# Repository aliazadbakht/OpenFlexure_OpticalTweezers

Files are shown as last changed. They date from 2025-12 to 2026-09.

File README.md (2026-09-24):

# OpenFlexure Optical Tweezers

An extension for the [OpenFlexure Microscope](https://openflexure.org/) that adds optical tweezers functionality. The OpenFlexure Project provides open-source, 3D-printed microscopes with precise mechanical positioning — this project extends that capability with laser-based optical trapping.

## Demo Video

Watch on YouTube (https://youtu.be/GGlHxX-9Ro8)

Full assembly walkthrough covering the basics, required parts, and what you need to get started. Click the thumbnail to watch on YouTube.

## Try the Interactive Simulation

**[Launch Web Simulation →](https://aliazadbakht.github.io/OpenFlexure_OpticalTweezers/)**

Experience optical tweezers physics directly in your browser! Click and drag particles, watch them escape the trap, and observe real-time Brownian motion. No installation required — works on any device.

---

## Table of Contents

- [Project Structure](#project-structure)
- [What's Included](#whats-included)
- [Installation](#installation)
- [Usage Guide](#usage-guide)
  - [Optical Tweezers Simulation](#1-optical-tweezers-simulation)
  - [Microrheology Simulation](#2-microrheology-simulation)
- [Building the Hardware](#building-the-hardware)
- [Bill of Materials](#bill-of-materials)
- [Acknowledgments](#acknowledgments)
- [License](#license)

---

## Project Structure

```
OpenFlexureOT/
├── README.md                          # This file
├── BOM.md                             # Bill of materials
├── LICENSE                            # CERN-OHL-S v2
├── index.html                         # GitHub Pages landing page
├── requirements.txt                   # Python dependencies (simulation)
│
├── Optical Tweezers Simulation/       # Interactive physics simulation
│   ├── opticaltweezers_simulation.py  # Desktop Python version
│   ├── index.html                     # Web version (PyScript, runs in browser)
│   ├── requirements.txt               # Python dependencies
│   ├── README.md                      # Simulation-specific documentation
│   └── DEPLOYMENT.md                  # GitHub Pages deployment guide
│
├── Microrheology Simulation/          # Browser-based microrheology demo
│   ├── Microrheology simulation.html
│   └── deploy/
│
├── openscad/                          # Parametric CAD files for customization
│   ├── cube_OT.scad
│   ├── laser_holder_OT.scad
│   ├── rms_optics_module_ot.scad
│   ├── cuppler_ot.scad
│   ├── alignment_cap.scad
│   ├── alignment_tool.scad
│   └── libs/
│
├── ipt/                               # Autodesk Inventor files (.ipt, .iam)
│
└── stl/                               # Ready-to-print STL and 3MF files
```

---

## What's Included

### CAD Files
- **`ipt/`** — Autodesk Inventor source files (.ipt/.iam) for modification in Fusion 360 or Inventor
- **`openscad/`** — Parametric OpenSCAD designs for customization (laser diameter, thread sizing, etc.)
- **`stl/`** — Ready-to-print STL and 3MF files for 3D printing

### Simulation Software
- **Optical Tweezers Simulation** — Interactive physics simulation (web + desktop)
- **Microrheology Simulation** — Browser-based microrheology demo

### Tractor-Beam Canvas Demo (Embeddable)
A lightweight, pure HTML/JS optical tweezers animation that runs in any browser. You can copy the canvas section and script from the main `index.html` and embed it into your own website — no dependencies required.

---

## Installation

### Prerequisites

- **Python 3.11+** (required for simulation software)
- **Git** (to clone the repository)

### Step 1: Clone the Repository

```bash
git clone https://github.com/aliazadbakht/OpenFlexureOT.git
cd OpenFlexureOT
```

### Step 2: Create a Virtual Environment (Recommended)

```bash
python -m venv venv

# On macOS/Linux:
source venv/bin/activate

# On Windows:
venv\Scripts\activate
```

### Step 3: Install Dependencies

```bash
pip install -r requirements.txt
```

---

## Usage Guide

### 1. Optical Tweezers Simulation

An interactive simulation of optical trap physics including Brownian motion, trap escape dynamics, and force visualization.

#### Web Version (No Installation)

Visit **[https://aliazadbakht.github.io/OpenFlexure_OpticalTweezers/](https://aliazadbakht.github.io/OpenFlexure_OpticalTweezers/)**

- Works on any device (desktop, tablet, mobile)
- First load takes 10–30 seconds (downloads Python runtime)
- Fully interactive with click-and-drag

#### Desktop Version

```bash
cd "Optical Tweezers Simulation"
pip install -r requirements.txt
python opticaltweezers_simulation.py
```

**Controls:**
- **Click and hold** on the particle to grab it
- **Drag** the particle around to move it
- **Release** inside the trap zone — the particle snaps back
- **Release** outside the escape radius — the particle escapes

**What you'll see:**
- Real-time Brownian motion of a trapped particle
- Green arrows showing trap force (in piconewtons)
- Position histogram with Boltzmann distribution overlay
- Time-series plot of particle position

---

### 2. Microrheology Simulation

Open `Microrheology Simulation/Microrheology simulation.html` in any web browser. No installation required.

---

## Building the Hardware

### Prerequisites

1. A 3D printer (PLA or PETG recommended)
2. OpenFlexure Microscope base — see [OpenFlexure documentation](https://openflexure.org/projects/microscope/)
3. Laser diode (typically 635 nm red, ~1 mW)
4. High-NA objective lens (NA >= 0.8, RMS threaded)
5. Optical components listed in [BOM.md](BOM.md)

### Assembly Steps

1. **Print the parts** — use the STL files from `stl/` or the combined `OpenFlexure Optical Tweezers.3mf`
2. **Install brass heat-set inserts** into the laser holder (3x M3)
3. **Mount the dichroic mirror** inside the optical cube
4. **Install the lenses** (f=17–20mm doublet and f=50mm doublet)
5. **Mount the laser** into the laser holder with adjustment screws
6. **Attach the coupler** between the cube and laser holder
7. **Install the objective** into the RMS optics module
8. **Mount onto the OpenFlexure Microscope** base

Watch the [assembly video](https://youtu.be/GGlHxX-9Ro8) for a detailed walkthrough.

### Customizing with OpenSCAD

The OpenSCAD files require dependencies from the main OpenFlexure project:

```bash
# 1. Clone the OpenFlexure Microscope repository
git clone https://gitlab.com/openflexure/openflexure-microscope.git

# 2. Install the threads library inside this project's OpenSCAD folder
cd OpenFlexureOT
git clone https://github.com/rcolyer/threads-scad.git openscad/threads-scad
```

Keep the folder structure like this:

```
your-workspace/
├── openflexure-microscope/
│   └── openscad/               # OpenFlexure base files
└── OpenFlexureOT/
    └── openscad/               # This project's files
        ├── threads-scad/
        ├── libs/
        └── *.scad
```

Customize parameters in the SCAD files:
- `laser_diameter` — match your laser diode size (default: 6 mm)
- Thread dimensions for your specific hardware
- Mounting geometry

Render and export STL files from OpenSCAD.

---

## Bill of Materials

See [BOM.md](BOM.md) for the full list of components including optical parts, fasteners, and electronics.

---

## Acknowledgments

This project is supported by **[Wavefront Principle B.V.](https://wfront.nl/)**, a pre-incubator dedicated to transforming innovative ideas into real-world devices.

It is also supported by **[Precisometer B.V.](https://www.precisometer.com)**, a company specialized in microscopy.

Special thanks to **[Mojtaba Nosratloo](https://www.linkedin.com/in/mojtaba-nosratlo-b62404a9/)** for his significant contributions to the design and development of this project.

---

## License

This project is licensed under the CERN Open Hardware Licence Version 2 — Strongly Reciprocal (CERN-OHL-S v2). See the [LICENSE](LICENSE) file for details.

This license is used because this project incorporates and builds upon OpenFlexure designs and components.

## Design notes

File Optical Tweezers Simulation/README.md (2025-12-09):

# Interactive Optical Tweezers Simulation

A real-time interactive simulation of optical tweezers (optical traps) using Python. Grab and manipulate a colloidal particle to observe trap dynamics, escape behavior, and thermal fluctuations.

## Features

🎯 **Interactive Particle Manipulation**
- Click and drag the particle to move it around
- Release inside the trap zone → particle bounces back to center
- Release outside the escape zone → particle escapes the optical trap
- Drag escaped particles back to recapture them

📊 **Real-time Visualization**
- **Top-down view**: See particle position and trajectory
- **Time series**: Track x-position over time relative to trap center
- **Histogram**: Distribution of particle positions (compared with Boltzmann theory)
- **Status indicators**: Visual feedback on trap state (trapped/dragging/escaped)
- **Force visualization**: Green arrow showing trap force magnitude and direction in real-time (piconewtons)

⚙️ **Physical Accuracy**
- Langevin equation with proper trap stiffness
- Realistic Brownian motion from thermal fluctuations
- Escape dynamics based on trap potential
- Boltzmann distribution for equilibrium predictions

## Requirements

- Python 3.8+
- NumPy
- Matplotlib
- SciPy

## Installation

```bash
git clone https://github.com/aliazadbakht/optical-tweezers-simulation.git
cd optical-tweezers-simulation
pip install -r requirements.txt
```

## Usage

Simply run the simulation:

```bash
python opticaltweezers_simulation.py
```

### Controls

| Action | Result |
|---|---|
| **Click particle** | Start dragging |
| **Drag** | Move particle to cursor |
| **Release inside orange circle** | Particle rebounds to trap center |
| **Release outside orange circle** | Particle escapes trap (Brownian motion only) |
| **Drag escaped particle back** | Recapture into trap |

## Physical Parameters

- **Particle**: 4 µm silica colloid
- **Laser power**: 5 mW @ 635 nm (red laser)
- **Trap stiffness**: 1.5 × 10⁻⁶ N/m
- **Temperature**: 293 K (20°C)
- **Medium**: Water (η = 0.001 Pa·s)
- **Escape radius**: 4 µm (beyond this, particle escapes)

## How It Works

The simulation integrates the Langevin equation:

$$m\frac{dv}{dt} = -\gamma v + F_{trap} + F_{thermal}$$

Where:
- $\gamma$ = friction coefficient from Stokes drag
- $F_{trap}$ = Harmonic trap force (when inside escape radius)
- $F_{thermal}$ = Random thermal forces
- $m$ = particle mass (negligible for small particles)

## Understanding the Visualization

### Trap Force Display
When dragging or holding the particle, a **green arrow** displays the trap force in real-time:
- **Arrow direction**: Points toward trap center (direction of force)
- **Arrow magnitude**: Scales with force strength
- **Force values**: Displayed in piconewtons (pN) for Fx, Fy, and |F|

The trap force follows Hooke's law: $$F = -k \cdot r$$

Where:
- $k$ = trap stiffness (1.5 × 10⁻⁶ N/m)
- $r$ = displacement from trap center

Typical force values at different positions:
- At trap center (r = 0): F = 0 pN
- At 1 µm displacement: F ≈ 1.5 pN
- At 4 µm (escape radius): F ≈ 6 pN

### Position Histogram
When the particle is trapped and near equilibrium, the histogram shows the **Boltzmann distribution** (black dashed line). This represents the theoretical probability of finding the particle at different positions due to thermal fluctuations.

The standard deviation of this distribution is:
$$\sigma = \sqrt{\frac{k_B T}{k}}$$

### Time Series
The x-position plot shows the particle's center coordinate relative to the trap center (0). The orange dashed lines indicate the escape radius boundaries.

## Applications

This simulation demonstrates:
- Optical trap fundamentals and dynamics
- Brownian motion and thermal noise
- Escape events and rare trajectory sampling
- Potential applications in:
  - Biophysics (protein pulling, molecular mechanics)
  - Colloidal science
  - Soft matter physics
  - Single-molecule studies

## Tips for Exploration

1. **Gentle Release**: Release the particle just outside the trap → watch it hover around the boundary before escaping
2. **Hard Pull**: Drag far and release → observe escape with asymmetric trajectory
3. **Recapture**: Escape a particle and drag it slowly back to observe re-entry dynamics
4. **Thermal Fluctuations**: At rest in the trap, the particle jitters randomly - this is Brownian motion!

## License

This simulation is part of the OpenFlexure Optical Tweezers project and is licensed under the CERN Open Hardware Licence Version 2 - Strongly Reciprocal (CERN-OHL-S v2).

## Author

Created for educational purposes in optical trapping and computational physics.

## References

- A. Ashkin, J. M. Dziedzic, J. E. Bjorkholm, and S. Chu, "Observation of a single-beam gradient force optical trap for dielectric particles," Opt. Lett. 11, 288-290 (1986)
- K. Berg-Sørensen and H. Flyvbjerg, "Power spectrum analysis for optical tweezers," Rev. Sci. Instrum. 75, 594-612 (2004)
- W. J. Greenleaf, M. T. Woodside, and S. M. Block, "High-resolution, single-molecule measurements of biomolecular motion," Annu. Rev. Biophys. Biomol. Struct. 36, 171-190 (2007)

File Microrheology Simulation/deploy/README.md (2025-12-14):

# Optical Tweezers Microrheology Simulation

An interactive simulation demonstrating passive microrheology using optical tweezers. Probe the viscoelastic properties of different media by analyzing the Brownian motion of a trapped bead.

## Features

🔬 **Multiple Media Types**
- **Newtonian Fluids**: Water, 50% Glycerol, 80% Glycerol
- **Viscoelastic Polymers**: Dilute PEO (0.1%), Semi-dilute (1%), Entangled (5%)
- **Gels**: Weak Agarose (0.1%), Strong Agarose (1%)

📊 **Real-time Visualizations**
- **Trapped Bead**: Watch Brownian motion change with medium properties
- **Dynamic Moduli**: G'(ω) and G''(ω) vs frequency (log-log plot)
- **Complex Viscosity**: |η*(ω)| vs frequency
- **Mean Square Displacement (MSD)**: Computed from particle trajectory

⚙️ **Physical Parameters**
- 2 µm silica bead
- 1 pN/µm trap stiffness
- Temperature: 293 K (20°C)
- Maxwell viscoelastic model

## Physics Background

### Microrheology Principles

Passive microrheology extracts viscoelastic properties from thermal fluctuations of embedded probe particles. The Mean Square Displacement (MSD) relates to the complex modulus through the Generalized Stokes-Einstein Relation.

### Dynamic Moduli

- **G' (Storage Modulus)**: Elastic/solid-like response - energy stored per cycle
- **G'' (Loss Modulus)**: Viscous/liquid-like response - energy dissipated per cycle

### Maxwell Model

For viscoelastic media:
- Short relaxation times: Liquid-like behavior (high G'')
- Long relaxation times: Gel-like behavior (high G')
- Crossover frequency indicates transition from viscous to elastic dominance

## How to Use

1. **Launch the simulation** by opening this page
2. **Select a medium** from the dropdown to change fluid properties
3. **Observe the bead motion** - see how Brownian motion varies with media
4. **Analyze the results**:
   - MSD curve shows particle displacement behavior
   - G' and G'' show elastic vs viscous contributions
   - Compare different media to understand viscoelasticity

## Applications

This simulation demonstrates principles used in:

- **Biophysics**: Cell mechanics, cytoplasm rheology
- **Soft Matter**: Polymer solutions, hydrogels
- **Pharmaceutical**: Drug delivery gel characterization
- **Food Science**: Texture analysis
- **Materials Science**: Complex fluid characterization

## Technical Details

- **Bead diameter**: 2 µm (silica)
- **Trap stiffness**: 1 pN/µm
- **Temperature**: 293 K (20°C)
- **Simulation**: PyScript (Python in browser)

## License

This simulation is part of the OpenFlexure Optical Tweezers project and is licensed under the CERN Open Hardware Licence Version 2 - Strongly Reciprocal (CERN-OHL-S v2).

---

**Questions?** Open an issue on the GitHub repository!

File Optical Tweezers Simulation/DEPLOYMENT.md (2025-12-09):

# Deploying the Optical Tweezers Simulation to GitHub Pages

This guide will help you deploy your interactive optical tweezers simulation to GitHub Pages so anyone can access it via a web browser.

## 🚀 Quick Deployment Steps

### Option 1: Deploy from the Repository Root (Recommended)

1. **Move the HTML file to the repository root:**
   ```bash
   cp "Optical Tweezers Simulation/index.html" index.html
   ```

2. **Commit and push to GitHub:**
   ```bash
   git add index.html
   git commit -m "Add PyScript optical tweezers simulation for GitHub Pages"
   git push origin main
   ```

3. **Enable GitHub Pages:**
   - Go to your repository on GitHub: `https://github.com/yourusername/OpenFlexureOT`
   - Click **Settings** → **Pages** (in the left sidebar)
   - Under **Source**, select **Deploy from a branch**
   - Under **Branch**, select `main` and `/ (root)`
   - Click **Save**

4. **Access your simulation:**
   - GitHub will provide a URL like: `https://yourusername.github.io/OpenFlexureOT/`
   - Wait 1-2 minutes for deployment to complete
   - Visit the URL to see your simulation!

### Option 2: Deploy from a Specific Folder

1. **Create a `docs` folder and move the file:**
   ```bash
   mkdir -p docs
   cp "Optical Tweezers Simulation/index.html" docs/index.html
   ```

2. **Commit and push:**
   ```bash
   git add docs/
   git commit -m "Add simulation to docs folder for GitHub Pages"
   git push origin main
   ```

3. **Enable GitHub Pages:**
   - Go to **Settings** → **Pages**
   - Select branch `main` and folder `/docs`
   - Click **Save**

4. **Access:** `https://yourusername.github.io/OpenFlexureOT/`

### Option 3: Deploy to a Separate Branch (gh-pages)

1. **Create and switch to gh-pages branch:**
   ```bash
   git checkout -b gh-pages
   ```

2. **Keep only the HTML file:**
   ```bash
   cp "Optical Tweezers Simulation/index.html" index.html
   git add index.html
   git commit -m "Initial GitHub Pages deployment"
   git push origin gh-pages
   ```

3. **Switch back to main:**
   ```bash
   git checkout main
   ```

4. **Enable GitHub Pages:**
   - Go to **Settings** → **Pages**
   - Select branch `gh-pages` and `/ (root)`
   - Click **Save**

## 📝 Important Notes

### First Load Time
- **Initial load takes 10-30 seconds** because PyScript downloads Python runtime and libraries
- Subsequent interactions are fast
- This is normal for PyScript applications

### Browser Compatibility
- Works best in **Chrome, Firefox, Edge, Safari** (latest versions)
- Requires JavaScript enabled
- Some older browsers may not support WebAssembly

### File Size
- The HTML file is self-contained (no external dependencies except PyScript CDN)
- All Python code is embedded in the HTML
- No need to upload additional files

## 🔧 Customization

### Update GitHub Link
In `index.html`, find this line and update with your actual GitHub username:
```html
<p>Built with PyScript | <a href="https://github.com/yourusername/OpenFlexureOT" target="_blank">View on GitHub</a></p>
```

Change `yourusername` to your actual GitHub username.

### Change Simulation Parameters
Edit the parameters in the `OpticalTrapSimulation.__init__()` method:
- `self.power` - Laser power (5.0e-3 = 5 mW)
- `self.wavelength` - Laser wavelength (635e-9 = 635 nm)
- `self.d_p` - Particle diameter (4.0e-6 = 4 µm)
- `self.stiffness` - Trap stiffness (1.5e-6 N/m)

## 🐛 Troubleshooting

### Simulation doesn't load
- Check browser console for errors (F12)
- Ensure you have a stable internet connection (PyScript loads from CDN)
- Clear browser cache and reload

### Simulation is slow
- This is expected on first load
- Close other browser tabs to free up memory
- Try a different browser (Chrome usually performs best)

### 404 Error on GitHub Pages
- Wait 2-5 minutes after enabling Pages
- Check that `index.html` is in the correct location
- Verify the branch/folder settings in GitHub Pages settings

## 🌐 Sharing Your Simulation

Once deployed, share your simulation with:
- **Direct link:** `https://yourusername.github.io/OpenFlexureOT/`
- **QR Code:** Generate a QR code pointing to your URL
- **Embed:** Can be embedded in other websites using an iframe

## 📚 Additional Resources

- [PyScript Documentation](https://pyscript.net/)
- [GitHub Pages Documentation](https://docs.github.com/en/pages)
- [Original Simulation](../Optical%20Tweezers%20Simulation/opticaltweezers_simulation.py)

## ✨ What's Different from the Python Version?

The PyScript version:
- ✅ Runs in any web browser (no Python installation needed)
- ✅ Can be hosted on GitHub Pages for free
- ✅ Same physics simulation and interactivity
- ✅ Same visual appearance
- ⏱️ Slower initial load time (10-30 seconds)
- 🌐 Requires internet connection for first load

## 🎓 For Academic Use

If using this simulation for teaching or research:
1. Consider adding a citation/acknowledgment section
2. You can modify the instructions for your specific use case
3. The simulation accurately represents Brownian motion in optical traps
4. Parameters are based on realistic experimental values

---

**Need help?** Open an issue on the GitHub repository!

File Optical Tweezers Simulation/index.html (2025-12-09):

# 🔬 Interactive Optical Tweezers Simulation

Real-time Brownian Motion in an Optical Trap

### 📋 How to Use:

- Click on the blue particle to grab it
- Drag it around the trap area
- Release inside the orange circle → particle bounces back to center (trapped!)
- Release outside the orange circle → particle ESCAPES!
- Drag back an escaped particle to recapture it
- Watch the green arrow show the trap force magnitude and direction

Loading simulation... (This may take 10-30 seconds on first load)

Simulates a 4µm silica bead in a 5mW optical trap at 635nm wavelength

Built with PyScript | View on GitHub (https://github.com/aliazadbakht/OpenFlexureOT)

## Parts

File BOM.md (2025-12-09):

# Bill of Materials (BOM)

## Optical Components

| Item | Specification | Quantity | Where to Buy |
|---|---|---|---|
| High-NA Objective Lens | NA ≥ 0.8, RMS threaded (search: "Plan infinity Achromatic Objective") | 1 | [AliExpress](https://nl.aliexpress.com/item/1005009852515331.html) |
| Red Laser Diode | ~1 mW (laser pointer), 635 nm typical | 1 | [Amazon](https://www.amazon.nl/-/en/dp/B07RM3RWSF?ref_=ppx_hzsearch_conn_dt_b_fed_asin_title_1) |
| Doublet Lens | Ø 12.7 mm (½"), f = 17–20 mm (search: "Double-Cemented Achromatic Lenses")| 1 | [AliExpress](https://nl.aliexpress.com/item/1005009623444048.html) |
| Doublet Lens | Ø 12.7 mm (½"), f = 50 mm (search: "Double-Cemented Achromatic Lenses")| 1 | [AliExpress](https://nl.aliexpress.com/item/1005009623444048.html) |
| Dichroic Mirror | Reflects red (~635 nm), pass blue, green 15x10x1.1mm  | 1 | [AliExpress](https://nl.aliexpress.com/item/4000835210707.html) |

## 3D-Printed Parts

| Item | File Location | Quantity | Where to Buy |
|---|---|---|---|
| Optical Cube | `stl/` folder | 1 | N/A - Print yourself |
| Cube-Laser Coupler | `stl/` folder | 1 | N/A - Print yourself |
| Laser Holder (3-screw adjust) | `stl/` folder | 1 | N/A - Print yourself |
| Additional mounting parts | `stl/OpenFlexure Optical Tweezers.3mf` | As needed | N/A - Print yourself |

## Hardware & Fasteners

| Item | Specification | Quantity | Where to Buy |
|---|---|---|---|
| Brass Heat-Set Inserts | M3 thread | 3 | [Amazon](https://www.amazon.nl/-/en/dp/B09ZHSGHXD?ref_=ppx_hzsearch_conn_dt_b_fed_asin_title_4&th=1) |
| M3 Screws | same as used in actuators/condenser (length as needed) | 3 | |
| M2 Self-Tapping Screws | For plastic parts | 4 | |
| M3 × 6 mm Screws | Machine screws | 2 | |

## Electronics (Optional)

| Item | Specification | Quantity | Where to Buy |
|---|---|---|---|
| DC-DC Buck/Boost Converter | Adjustable output to match laser voltage | 1 | [Amazon](https://www.amazon.nl/-/en/dp/B0D7BWSTCX?ref_=ppx_hzsearch_conn_dt_b_fed_asin_title_3) |
| USB Power Adapter | 5V output (if powering via USB) | 1 | |

## Notes

- **Objective Lens**: Must be high numerical aperture (NA ≥ 0.8) for effective optical trapping. RMS thread compatible with OpenFlexure microscope.
- **Laser Safety**: Use appropriate eye protection when working with lasers, even low-power ones.
- **3D Printing**: All STL files are in the `stl/` folder. Print with standard PLA or PETG.
- **Brass Inserts**: Install with soldering iron or heat-set tool before assembly.
- **DC-DC Converter**: Only needed if your laser operating voltage differs from your power supply (e.g., laser needs 3V but you have 5V USB).

## OpenFlexure Base Components

This extension requires a complete OpenFlexure Microscope base. See the [OpenFlexure documentation](https://openflexure.org/projects/microscope/) for the full microscope BOM.

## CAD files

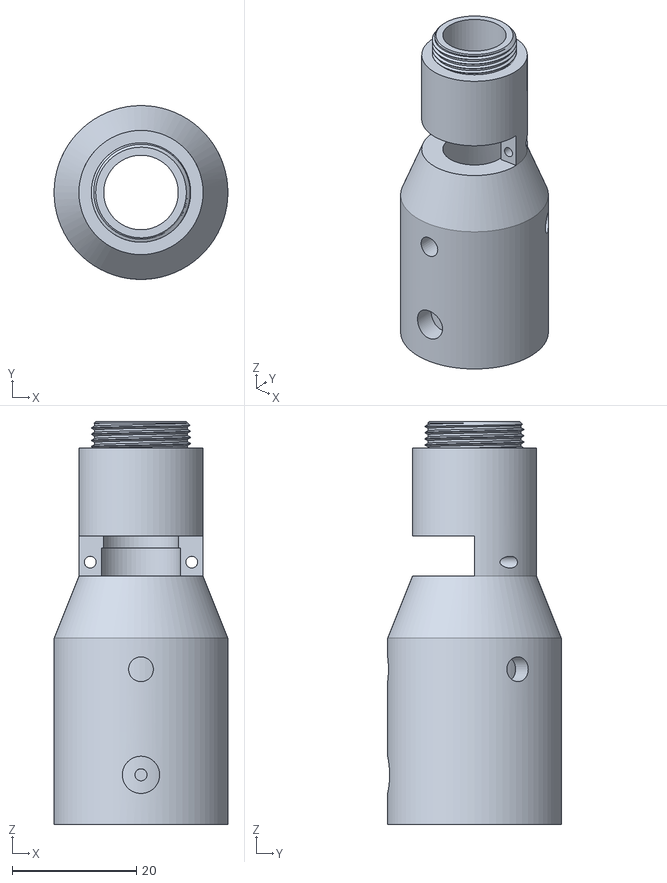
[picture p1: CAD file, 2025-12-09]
stl/Laser Holder 12 mm laser.stl
28.0 x 28.0 x 64.9

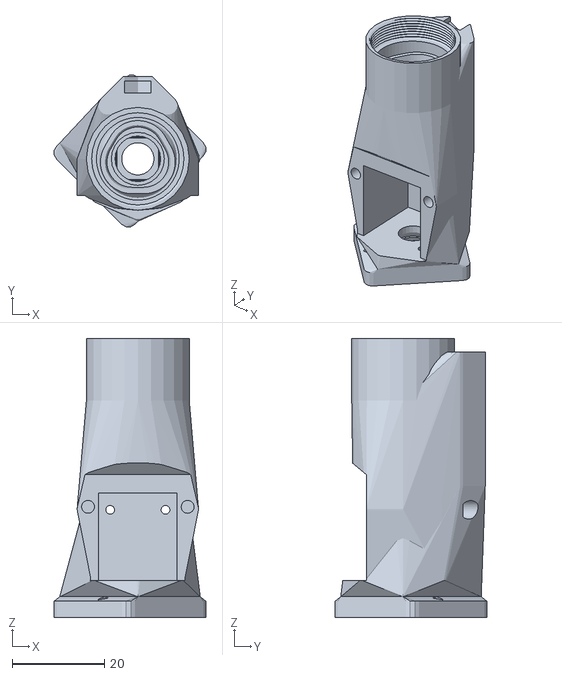
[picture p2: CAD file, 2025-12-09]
stl/RMS optics module OT.stl
32.9 x 32.9 x 60.5

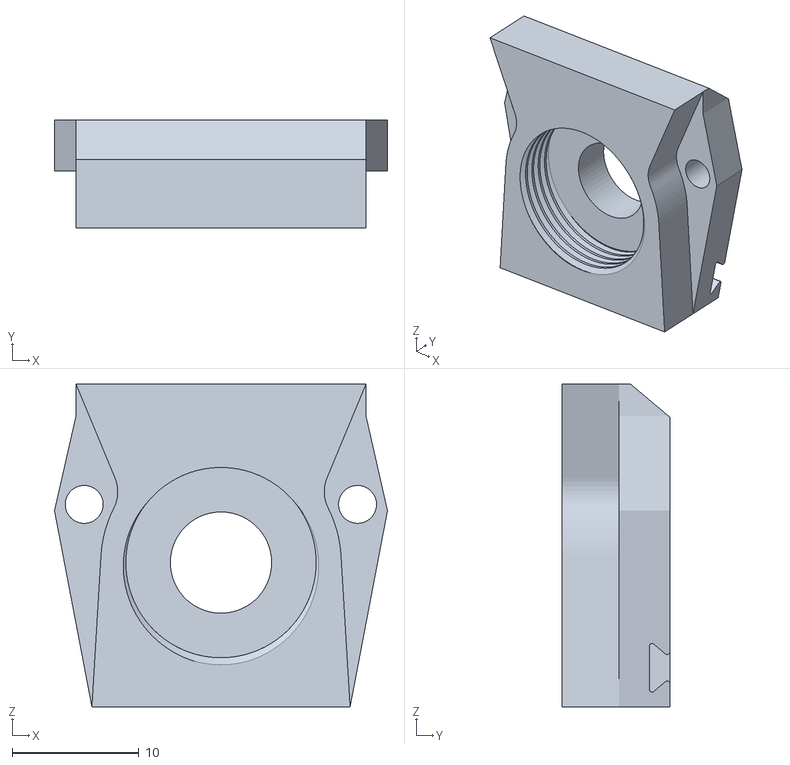
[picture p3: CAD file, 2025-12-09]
stl/Cuppler.stl
26.3 x 8.50 x 25.5

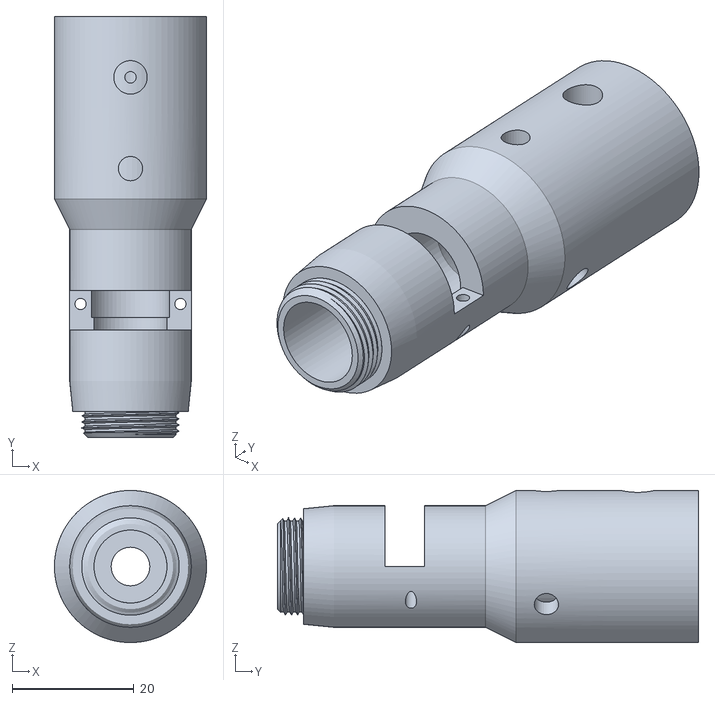
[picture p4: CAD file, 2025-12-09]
stl/laser Holder 6 mm laser .stl
25.0 x 69.2 x 25.0

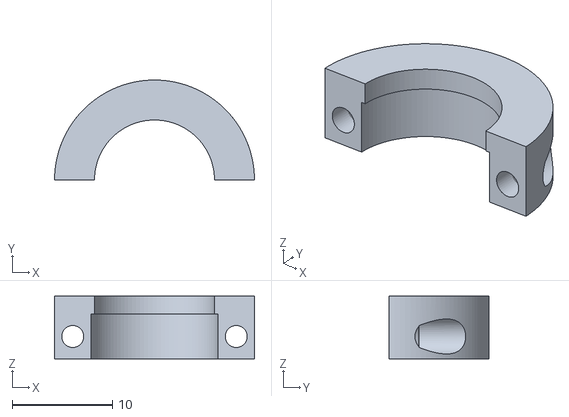
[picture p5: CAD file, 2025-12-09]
stl/Lens Lid.stl
20.0 x 10.0 x 6.30

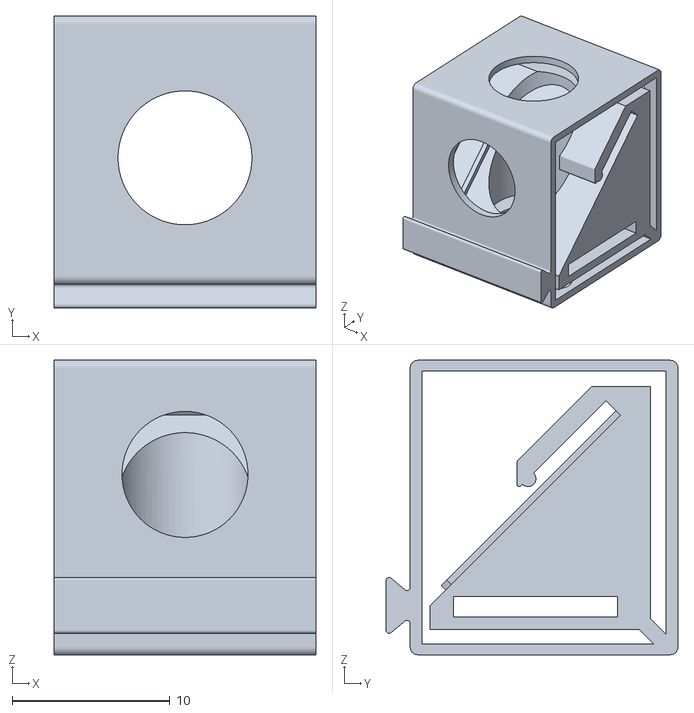
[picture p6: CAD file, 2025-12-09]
stl/Cube.stl
16.6 x 18.5 x 18.7

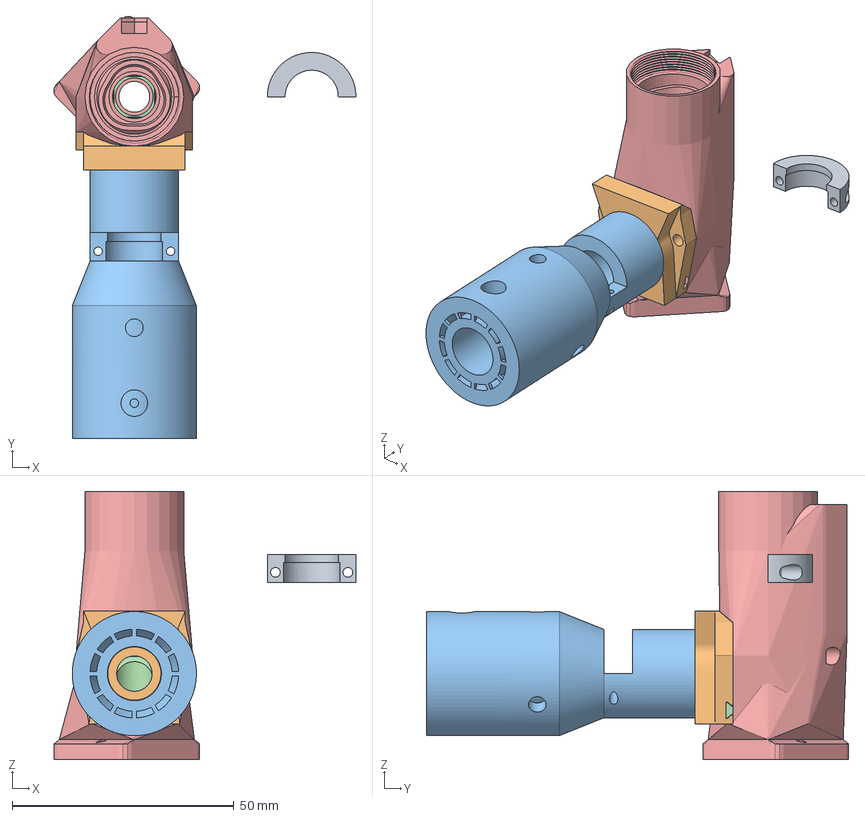
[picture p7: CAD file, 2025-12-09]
stl/OpenFlexure Optical Tweezers.3mf
68.1 x 95.2 x 60.5 mm
Cut Threaded
In
Objective Holder

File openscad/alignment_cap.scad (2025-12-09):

// Parameters
outer_d    = 20.1; // mm
thickness  = 2;    // mm
height     = 50;   // mm
inner_d    = 16.1; // 16.1 mm
bottom_t   = 6;    // mm
pinhole_size = 2;

// Handle parameters
handle_length = 20;   // mm - how far the handle extends
handle_width = 6;     // mm - width of the handle
handle_thickness = 3; // mm - thickness of the handle
handle_hole_d = 4;    // mm - diameter for loop handle hole

// Bottom cap with 2 mm pinhole
module bottom_cap_with_pinhole() {
  difference() {
    cylinder(h = bottom_t, d = inner_d, $fn = 128);      // the cap (d=16.1)
    translate([0, 0, -0.05])                           // small Z fudge
      cylinder(h = bottom_t + 0.1, d = pinhole_size, $fn = 48); // Ø2 mm hole
  }
}

// Option 1: Simple tab handle
module tab_handle() {
  translate([inner_d/2-2, -handle_width/2, 0])
    cube([handle_length, handle_width, handle_thickness]);
}

// Option 2: Rounded tab handle
module rounded_tab_handle() {
  translate([inner_d/2, 0, handle_thickness/2])
    rotate([0, 90, 0])
      hull() {
        cylinder(h = handle_length, d = handle_thickness, $fn = 32);
        translate([0, 0, 0])
          cylinder(h = handle_length, d = handle_width, $fn = 32);
      }
}

// Option 3: Loop handle
module loop_handle() {
  translate([inner_d/2 + handle_length/2, 0, bottom_t/2])
    rotate([90, 0, 0])
      difference() {
        cylinder(h = handle_thickness, d = handle_length, $fn = 64, center = true);
        cylinder(h = handle_thickness + 0.1, d = handle_hole_d, $fn = 32, center = true);
      }
}

// Option 4: Ergonomic curved handle
module curved_handle() {
  translate([inner_d/2, 0, 0]) {
    rotate_extrude(angle = 45, $fn = 64) {
      translate([handle_length/1.5, 0, 0])
        circle(d = handle_thickness, $fn = 16);
    }
  }
}

// Choose your handle style by uncommenting one of these:

// Option 1: Simple tab handle
union() {
  bottom_cap_with_pinhole();
  tab_handle();
}

// Option 2: Rounded tab handle  
// union() {
//   bottom_cap_with_pinhole();
//   rounded_tab_handle();
// }

// Option 3: Loop handle
// union() {
//   bottom_cap_with_pinhole();
//   loop_handle();
// }

// Option 4: Ergonomic curved handle
// union() {
//   bottom_cap_with_pinhole();
//   curved_handle();
// }

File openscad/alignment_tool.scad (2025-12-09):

// Parameters
outer_d   = 20.3;   // mm
thickness = 1;    // mm
height    = 100;   // mm
inner_d   = outer_d - 2*thickness;  // 16 mm
bottom_t  = 2;    // mm
pinhole_size = 1;
// Hollow tube

module tube() {
  difference() {
//      this is the main tube
    cylinder(h = height, d = outer_d, $fn = 128);
    translate([0, 0, -0.05])
      cylinder(h = height + 0.1, d = inner_d, $fn = 128);Í
  }
}Í

// Bottom cap with 1 mm pinhole
module bottom_cap_with_pinhole() {
  difference() {
    cylinder(h = bottom_t, d = inner_d, $fn = 128);     // the cap
    translate([0, 0, -0.05])                             // small Z fudge
      cylinder(h = bottom_t + 0.1, d = pinhole_size, $fn = 48);     // Ø1 mm hole
  }
}

// Assembly
union() {
  tube();
  bottom_cap_with_pinhole();
}

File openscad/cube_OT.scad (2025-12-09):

// --- Parameters ---
outer_size = 18;       // Outer dimensions (mm)
wall_thickness = 1;    // Wall thickness (mm)
wedge_leg = 14.5;      // Length of the triangle legs
wedge_width = 16;      // Width of the wedge
connector_size = 1.5;  // Size of the tiny attachment piece
hole_diameter = 8.5;   // Diameter of the round holes

// New Plate Parameters
plate_dist_from_corner = 9; 
plate_thickness = 1.1;      
plate_length = 9;           // Extracted length for calculation
rod_diameter = 1.5;         // Controls the size of the rod

// Slot Parameters
slot_width = 10;       // X direction
slot_height = 1.1;     // Z direction (thickness)

// Small side hole parameters (on -X and -Z faces)
side_hole_diameter = 3;      // Diameter of small holes
side_hole_offset   = 3;    // Distance from top and right edges (mm)

// Calculate inner size
inner_size = outer_size - 2 * wall_thickness; // 15mm

// --- Main Cube Body as a module ---
module cube_body() {

    difference() {

        // 1. The Positive Object (Frame + Wedge + Connector + NEW PLATE + TRAPEZOID BAR)
        union() {
            // The Hollow Frame
            difference() {
                cube([outer_size-1, outer_size-2, outer_size], center = true);
                cube([inner_size, inner_size, inner_size], center = true);
                cube([inner_size, outer_size + 2, inner_size], center = true);
            }

            // The 45-Degree Wedge
            translate([
                -inner_size/2 + 0.5, 
                0, 
                -inner_size/2 + 0.5
            ])
            rotate([90, 0, 0])
            linear_extrude(height = wedge_width, center = true)
            polygon(points=[
                [0, 0],            
                [wedge_leg, 0],    
                [0, wedge_leg]     
            ]);

            // --- NEW: The Parallel 45-Degree Plate & Connector ---
            // gripper
            rotate([0, 225, 0]) {
                
                // 1. The Floating Plate (Original)
                translate([4, 0, -1.2]) 
                cube([plate_length, wedge_width, plate_thickness], center=true); 

                // The Tiny Rod Below
                translate([0, 0, -1]) 
                rotate([90, 0, 0]) // Rotates cylinder to lay flat
                rotate([0,0,0])   // Runs along the Y axis (width)
                cylinder(d=rod_diameter, h=wedge_width, center=true, $fn=30);

                // 2. The Tiny Connector 
                rotate([0, 45, 0]){
                    translate([wedge_width/2-1.5, 0, wedge_width/2-2])
                    cube([1.5, wedge_width, 3], center=true);
                }
            }

            // The Tiny Connector (Original corner piece)
            translate([
                -inner_size/2 + connector_size/2, 
                0, 
                -inner_size/2 + connector_size/2
            ])
            cube([connector_size, wedge_width, connector_size], center=true);
            
            // --- NEW: Positive Trapezoid Bar on +X wall ---
            // This protrudes outward and will fit into the illuminator holder slot in cuppler_ot.scad
            translate([outer_size/2 + 0.7, -outer_size/2+1, -6.5]) {
                rotate([0, 90, 90]) {
                    scale([1.04, 1.3, 1.0]) {
                        trapezoid_bar();
                    }
                }
            }
        }

        // 2. The Negative Shapes (Holes)
        
        // Hole A: Vertical (Z-axis) cylinder
        cylinder(d = hole_diameter, h = outer_size + 2, center = true, $fn=100);

        // Hole B: Horizontal (+X wall) cylinder
        translate([outer_size/2, 0, 0]) 
        rotate([0, 90, 0])              
        cylinder(d = hole_diameter, h = 5, center = true, $fn=100); 

        // Hole C: Rectangular Slot in the Wedge
        translate([
            -0.8, 
            0, 
            -inner_size/2 + 0 + 2 
        ])
        cube([slot_width, outer_size + 5, slot_height], center = true);

        // --- Small 3 mm circular hole on -X side ---
        translate([
            -outer_size/2,                               // On the -X wall
            (outer_size - 2)/2 - side_hole_offset,       // 2.5 mm from right edge (Y+)
            outer_size/2 - side_hole_offset              // 2.5 mm from top edge (Z+)
        ])
        rotate([0, 90, 0])                               // Hole axis along X
        cylinder(d = side_hole_diameter, h = 2, center = true, $fn = 60);

        // --- Small 3 mm circular hole on -Z side ---
        translate([
            outer_size/2 - side_hole_offset -0.5,             // 2.5 mm from right edge (X+)
            (outer_size - 2)/2 - side_hole_offset ,       // 2.5 mm from top edge (Y+)
            -outer_size/2                                // On the -Z wall
        ])
        cylinder(d = side_hole_diameter, h = 2, center = true, $fn = 60);
    }
}

// --- Trapezoid Bar Module Definition ---
module trapezoid_bar(large_side=4, small_side=2, trapezoid_height=1, length=16) {
    points = [
        [-large_side / 2, 0],
        [large_side / 2, 0],
        [small_side / 2, trapezoid_height],
        [-small_side / 2, trapezoid_height]
    ];
    
    linear_extrude(height = length) {
        polygon(points);
    }
}

// Default render for standalone viewing
rotate([90,0,0])
    cube_body();

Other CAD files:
openscad/cuppler_ot.scad
ipt/Cube .ipt
ipt/Laser Holder 3.0 .iam
ipt/Lid.ipt
ipt/Objective Holder.ipt
ipt/OpenFlexure Optical Tweezers.iam
ipt/Part10.ipt
ipt/cuppler_ot.ipt
openscad/laser_holder_OT.scad
openscad/rms_optics_module_ot.scad
